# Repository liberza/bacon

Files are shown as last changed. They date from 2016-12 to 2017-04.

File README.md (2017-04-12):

# bacon - Balloon Ascent Controller

The goal of this project is to control the rate of ascent of two high-altitude
balloons, to keep at the same relative altitude as they ascend. 

A simulator is included in simulator/. Run tongs.py to start, then open client.html
in a browser. Power up the two payloads to begin auto-discovery. Once that is finished, 
the simulated flight begins and shows a live plot of progress.

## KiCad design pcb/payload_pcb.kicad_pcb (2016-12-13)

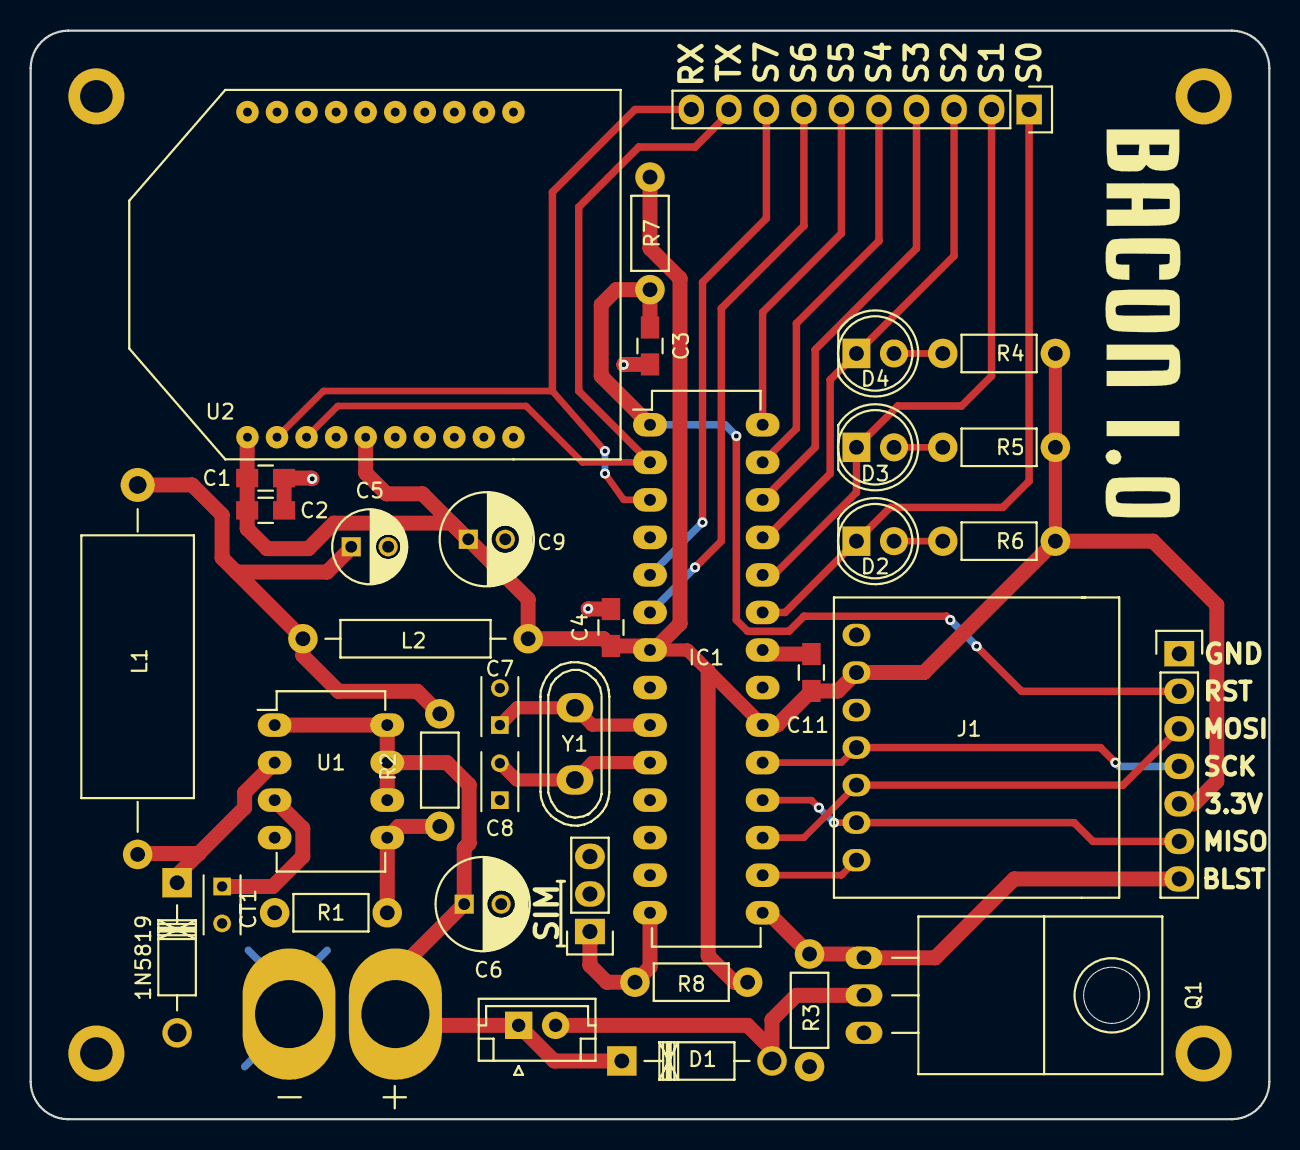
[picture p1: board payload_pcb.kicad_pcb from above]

Board: 2 copper layers, 83.8 x 73.7 mm, 37 parts (0 on the bottom side), 30 nets.

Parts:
1N5819: D5; Diode_DO-41_SOD81_Horizontal_RM10
C1, C2, C4, C11: CP1; C_0805_HandSoldering
C3: 0.1uF; C_0805_HandSoldering
C5: 22uF; C_Radial_D5_L11_P2.5
C6: 100 uF; C_Radial_D6.3_L11.2_P2.5
C7, C8: 22p; C_Rect_L4_W2.5_P2.5
C9: 100uF; C_Radial_D6.3_L11.2_P2.5
CT1: 160 pF; C_Rect_L4_W2.5_P2.5
D1: D; Diode_DO-41_SOD81_Horizontal_RM10
D2: Green; LED-5MM
D3: Yellow; LED-5MM
D4: Red; LED-5MM
IC1: ATMEGA328-P; DIP-28_W7.62mm_LongPads
J1: MS5607_Module
L1: 50 uH; Choke_Horizontal_RM25mm
L2: 1 uH; Choke_Horizontal_RM15mm
P1: BAT_TERMINALS; XT60
P2: CONN_01X10; Pin_Header_Straight_1x10
P3: CONN_01X03; Pin_Header_Straight_1x03
P4: CONN_01X07; Pin_Header_Straight_1x07
P5: VALVE; JST_EH_B02B-EH-A_02x2.50mm_Straight
Q1: Q1; TO-220_Neutral123_Horizontal
R1: 22k; Resistor_Horizontal_RM7mm
R2: 36k; Resistor_Horizontal_RM7mm
R3, R7: 4.7k; Resistor_Horizontal_RM7mm
R4, R5, R6: 270; Resistor_Horizontal_RM7mm
R8: 4.7K; Resistor_Horizontal_RM7mm
U1: MC33063A; DIP-8_W7.62mm_LongPads
U2: XBee_S3B
Y1: Crystal; Crystal_HC50-U_Vertical

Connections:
3.3V: C1.1, C2.1, C4.1, C9.1, C11.1, IC1.7, IC1.20, J1.2, L2.1, P4.5, R4.2, R5.2, R6.2, R7.1, R8.1, U2.1, U2.5
BALLAST: IC1.15, P4.7, Q1.1, R3.1
CSB: IC1.16, J1.7
GND: 1N5819.2, C1.2, C2.2, C3.2, C4.2, C5.2, C6.2, C7.2, C8.1, C9.2, C11.2, CT1.2, IC1.8, IC1.22, J1.1, J1.3, P1.1, P3.2, P3.3, P4.1, Q1.3, R1.2, R3.2, U1.4, U2.10
MISO: IC1.18, J1.6, P4.6
MODE: IC1.14, P3.1, R8.2
MOSI: IC1.17, J1.5, P4.3
unnamed: 1N5819.1, L1.1, U1.2
unnamed: C5.1, L1.2, L2.2, R2.2
unnamed: C7.1, IC1.9, Y1.1
unnamed: C8.2, IC1.10, Y1.2
unnamed: CT1.1, U1.3
unnamed: D1.2, P5.2, Q1.2
unnamed: D2.2, R6.1
unnamed: D3.2, R5.1
unnamed: D4.2, R4.1
unnamed: R1.1, R2.1, U1.5
RESET: C3.1, IC1.1, P4.2, R7.2
SCK: IC1.19, J1.4, P4.4
STATUS0: D2.1, IC1.23, P2.1
STATUS1: D3.1, IC1.24, P2.2
STATUS2: D4.1, IC1.25, P2.3
STATUS3: IC1.26, P2.4
STATUS4: IC1.27, P2.5
STATUS5: IC1.28, P2.6
STATUS6: IC1.6, P2.7
STATUS7: IC1.5, P2.8
VDD: C6.1, D1.1, P1.2, P5.1, U1.1, U1.6, U1.7, U1.8
XBEE_RX: IC1.3, P2.10, U2.2
XBEE_TX: IC1.2, P2.9, U2.3

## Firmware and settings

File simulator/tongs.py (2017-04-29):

#!/usr/bin/python3
import numpy as np
from datetime import datetime, timedelta
import time
import binascii
import websockets
import asyncio
import json

# local imports
from payload import Payload
from xbee import XBee
from liveplot import LivePlot
import bmp

# make this commandline args at some point. for now, this is completely fine.
MASS1 = 3.4
MASS2 = 3.3
#BALLAST = 0.581 # half liter bottle capacity, minus 10ml
BALLAST = 0.8 # 2L bottle filled halfway with 0.8kg/L isopropyl alcohol
PROFILE = "profiles/umhab52.json"

# Let's simulate some balloons.

async def run_sim(websocket, path):
    try:
        # If your XBee is somewhere else, change this.
        xb = XBee("/dev/xbee", 1200)
    except:
        print("XBee not connected. Try plugging it in or changing the default from /dev/xbee.")
        exit()

    # two payloads
    p1 = Payload(PROFILE, MASS1, BALLAST, "P1")
    p2 = Payload(PROFILE, MASS2, BALLAST, "P2")

    # First order of business: figure out who's who.
    print("Performing initial peering...")
    bmp.init_peering(p1, p2, xb)

    # Ok, we have two payloads.
    # Wait for one to request an altitude.
    print("Waiting for initial altitude requests...")

    launched = False
    time_launched = None
    p1_ready = False
    p2_ready = False
    p1_landed = False
    p2_landed = False
    while((p1_landed == False) or (p2_landed == False)):
        msg = None
        # just listen. the payloads will ask for altitudes.
        while(msg == None):
            msg = xb.rx()

        parsed = bmp.parse(msg)
        msg_type = parsed[0]

        if (msg_type == bmp.MSG_TYPES['WAT_REQUEST']):
            # Say "I am a simulator"
            addr = int.from_bytes(parsed[2], byteorder="big")
            xb.tx(parsed[1], addr)
        elif (msg_type == bmp.MSG_TYPES['ALT_REQUEST']):
            # Time to simulate.
            addr = int.from_bytes(parsed[1], byteorder="big")
            if (addr == p1.addr):
                p1_ready = True
                cur_p = p1
            elif (addr == p2.addr):
                p2_ready = True
                cur_p = p2
            else:
                print("Another payload?")
                continue
            
            ballast_time_ms = parsed[2]
            cur_p.drop_mass(ballast_time_ms)
            cur_time = time.time()
            last_time = cur_p.last_request_time
            last_alt_m = cur_p.last_alt/10.0
            if (launched):
                #cur_p.adjust_time(cur_time)
                p1.adjust_time(cur_time)
                p2.adjust_time(cur_time)
            else:
                #cur_p.last_request_time = cur_time
                p1.last_request_time = cur_time
                p2.last_request_time = cur_time
            # Send them their current alt.
            if (cur_p.alt() is not None):
                alt = cur_p.alt()
                cur_p.last_alt = alt
                # send the payload's alt
                xb.tx("s" + str(int(alt)), cur_p.addr)

                timestamp = datetime.fromtimestamp(cur_time).strftime("[%H:%M:%S]")
                #alt_m = cur_p.alt()/10.0 # decimeters to meters
                #speed = (alt_m-last_alt_m)/(cur_time-last_time)
                p1_alt_m = p1.alt()/10.0
                p2_alt_m = p2.alt()/10.0
                #if (speed == None):
                #    speed = 0
                #print("{0} {1}: alt={2:.1f}m speed={3:.2f}m/s mass={4:.3f}kg drop_time={5}".format(timestamp,cur_p.name,alt_m,speed,cur_p.mass,ballast_time_ms))
                #print("P1 alt: {0}, P2 alt: {1}, Delta alt: {2}, P1 mass: {3}, P2 mass: {4}".format(p1_alt_m, p2_alt_m, p1_alt_m - p2_alt_m, p1.mass, p2.mass))
                await websocket.send('{{"p1_a": {0}, "p2_a": {1}, "p1_m": {2}, "p2_m": {3}, "dist": {4}}}'.format(p1_alt_m, p2_alt_m, p1.mass, p2.mass, p1_alt_m - p2_alt_m))

                # update graph
                #if (time_launched is not None):
                    #if (cur_p.name == "P1"):
                        #lp.update_line(cur_time - time_launched, alt_m, p1_line)
                    #elif (cur_p.name == "P2"):
                        #lp.update_line(cur_time - time_launched, alt_m, p2_line)
            else:
                # if alt is None, the payload finished simulation.
                if (cur_p.addr == p1.addr):
                    p1_landed = True
                elif (cur_p.addr == p2.addr):
                    p2_landed = True
                continue
            
            if (p1_ready and p2_ready and launched == False):
                launched = True
                time_launched = time.time()
                time_elapsed = 0
                print("Launched!")

        elif (msg_type == bmp.MSG_TYPES['WAT_REQUEST']):
            # Respond, saying "I am the simulator".
            addr = int.from_bytes(parsed[2], byteorder="big")
            xb.tx(parsed[1], addr)


if __name__ == "__main__":
    # ASCII art adapted from www.chris.com/ASCII/index.php?art=objects/balloons
    print('''
          ,'````',
    .`',.'        `..'``',      ____
  ,'                     `', .-'    '-.                                 
 ;                        ..' /)       '.         ,'``',  ,..,   ,..,
  ',            ,.,    .'`/  (/          \     ,.'      '`    '.'    ;
    '.,.`'.,,,.`   `''`  ;                ;  ,`                       ',
                         |                | ;                           ;
                         |                | `.,     ;    ,...         ,'
             ____        ;                ;    `.,.' `,.'    `,.     ;
          .-'    '-.      \              /                      `.,,'
        .' /)       '.     '.          .'   
       /  (/          \      '-._  _.-'      
      ;                ;         )(           
      |                |        (__)          
      |    ( ͡° ͜ʖ ͡°)    |         /            ╔╦╗╔═╗╔╗╔╔═╗╔═╗
      ;                ;         |             ║ ║ ║║║║║ ╦╚═╗
       \              /          ;             ╩ ╚═╝╝╚╝╚═╝╚═╝
        '.          .'          /     The on-ground simulator for BACON
          '-._  _.-'          |--|        
              )(              |  |    
             (__)             |__|     
              |                ;     
              |                /
              |               ;  
              ;               ;
''')
    print("Waiting for websocket connection...")
    start_server = websockets.serve(run_sim, '127.0.0.1', 5678)
    asyncio.get_event_loop().run_until_complete(start_server)
    asyncio.get_event_loop().run_forever()

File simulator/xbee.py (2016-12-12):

#!/usr/bin/python3
import serial
import queue
import time
import binascii

# class for managing XBee API mode 
class XBee():
    # Bytes which need to be escaped in frames
    SPECIAL_BYTES = {
        'FRAME_DELIM':  0x7E,
        'ESCAPE':       0x7D,
        'XON':          0x11,
        'XOFF':         0x13,
    }

    # Digimesh broadcast addr
    BROADCAST = 0x000000000000FFFF

    # Digimesh frame types
    FRAME_TYPES = {
        'AT':           0x08,
        'AT_QPV':       0x09,
        'TX':           0x10,
        'EXPLICIT_TX':  0x11,
        'REMOTE':       0x17,
        'AT_RESP':      0x88,
        'MODEM_STATUS': 0x8A,
        'TX_STATUS':    0x8B,
        'ROUTE_INFO':   0x8D,
        'RX':           0x90,
        'EXPLICIT_RX':  0x91,
        'NODE_ID':      0x95,
        'REMOTE_RESP':  0x97,
    }

    BUF_FULL_TIMEOUT = 5

    # queue to hold validated frames
    rx_queue = queue.Queue()
    # buffer to hold partial frames
    rx_buf = bytearray()

    def __init__(self, devfile, baud):
        self.serial = serial.Serial(port=devfile, 
                                    baudrate=baud,
                                    parity=serial.PARITY_NONE,
                                    stopbits=serial.STOPBITS_ONE,
                                    bytesize=serial.EIGHTBITS
                                    )
        self.serial.flush()
        self.max_frame = 255

    def tx(self, data, dest=0x000000000000FFFF, opts=0x00):
        '''
        data is an unescaped string.
        dest is the 64-bit digimesh address to tx to.
        opts are the frame options.
        '''
        frame_size = len(data) + 14     # tx api frame has 14 bytes overhead
        if (frame_size > self.max_frame):
            print("Frame too long, not sending.")
            return False

        frame = bytearray(((frame_size >> 8) & 0x0FF, 
                           (frame_size & 0x0FF),
                           self.FRAME_TYPES['TX'],
                           0x00,
                           # destination
                           (dest >> 56) & 0x0FF,
                           (dest >> 48) & 0x0FF,
                           (dest >> 40) & 0x0FF,
                           (dest >> 32) & 0x0FF,
                           (dest >> 24) & 0x0FF,
                           (dest >> 16) & 0x0FF,
                           (dest >> 8) & 0x0FF,
                           (dest & 0x0FF),
                           0xFF, # reserved
                           0xFE, # reserved
                           0x00, # broadcast radius (default 0x00 for radius=max hops)
                           0x00, # tx options (default, use whatever is already set)
                           ))

        # append the data
        frame += bytearray(data.encode())

        # append checksum
        frame.append(0xFF - (sum(frame[2:]) & 0x0FF))
        
        # escape the frame
        frame = self.escape(frame)

        # prepend the unescaped delimiter
        frame = bytearray(b'\x7E') + frame

        return self.serial.write(frame)

    def rx(self):
        '''
        Read bytes from serial if any are waiting.
        Then validate frames and add to rx_queue.
        '''
        received = False
        num_bytes = self.serial.in_waiting
        self.rx_buf.extend(self.serial.read(num_bytes))
        # each sequence is a frame. split at the delimiter.
        sequence = self.rx_buf.split(bytes(b'\x7E'))        
        for s in sequence:
            frame = self.validate_frame(s)
            if (frame is not None):
                self.rx_queue.put(frame, self.BUF_FULL_TIMEOUT)
                received = True

        if (received == True):
            self.rx_buf = bytearray()
            return self.rx_queue.get()

        else:
            return None

    def parse_frame(self, frame):
        '''
        Parse a frame. Figure out what type it is, and return the relevant data.
        '''
        for frametype, value in self.FRAME_TYPES.items():
            if frame[2] == value:
                break;

        if (value == self.FRAME_TYPES['AT_RESP']):
            pass
        elif (value == self.FRAME_TYPES['MODEM_STATUS']):
            pass
        elif (value == self.FRAME_TYPES['TX_STATUS']):
            pass
        elif (value == self.FRAME_TYPES['ROUTE_INFO']):
            pass
        elif (value == self.FRAME_TYPES['RX']):
            source = frame[3:10]
            opts = frame[13]
            data = frame[14:-1]
            return data
        elif (value == self.FRAME_TYPES['EXPLICIT_RX']):
            pass
        elif (value == self.FRAME_TYPES['TX']):
            # just for debugging. the only time this should ever show up is
            # if you have a serial cable hooked up to the TX pin of the xbee.
            pass
        elif (value == self.FRAME_TYPES['NODE_ID']):
            pass
        elif (value == self.FRAME_TYPES['REMOTE_RESP']):
            pass
        else:
            raise Exception("Frame has invalid frame type.")
        return None

    def escape(self, data):
        ''' Put an escape character before a special character, and escape it. '''
        escaped = bytearray()
        for byte in data:
            if byte in self.SPECIAL_BYTES.values():
                escaped.append(self.SPECIAL_BYTES['ESCAPE'])
                escaped.append(byte ^ 0x20)
            else:
                escaped.append(byte)
        return escaped

    def unescape(self, data):
        ''' Think "escape", but the opposite of that. '''
        unescaped = bytearray()
        last_escaped = False
        # create an iterator from range() so we can use next() on it
        q = iter(range(len(data)))
        for i in q:
            if (last_escaped):
                unescaped.append(data[i] ^ 0x20)
                last_escaped = False
            elif data[i] == self.SPECIAL_BYTES['ESCAPE']:
                last_escaped = True
            else:
                unescaped.append(data[i])
        return unescaped
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

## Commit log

2016-10-11 add serial.c. modify definition of serial_init() to allow for easier configuration of UART.
2016-10-16 much progress on XBee.tx(). untested beyond watching the TX LED light up on the breakout board when running it.
2016-10-16 functions for initializing gpio and operating solenoid valve
2016-10-16 add XBee.rx(). need to do frame validation
2016-10-16 fixed a few bugs. checksum now verifies correctly and length is computed properly
    [xbee.py]
2016-10-16 reorganize constants, add new FRAME_TYPES dict of constants.
2016-10-16 interrupt reads byte and writes to buffer.
2016-10-16 simplified interrupt routine
2016-10-23 fix all compilation warnings and errors. ISR() is a macro, not a function to declare.
    [xbee.py]
2016-10-23 move ISR for rx to xbee.c, because it will swap buffers when frame delimiter is reached.
2016-10-23 use SPECIAL_BYTES instead of hardcoding frame delim
2016-10-24 fix frame_types and special_bytes declarations
2016-10-27 make interrupt rx buffer volatile
2016-11-06 replacing pingpong.h/c with rbuf.h/c. a ring buffer is more appropriate for this use-case.
2016-11-11 fix xbee.py. seems to work great now.
    [xbee.py]
2016-11-11 fix frame parsing
2016-11-11 fixing parse frame and checksum in xbee.py. also confirmed that unescaping in xbee.c seems to work fine.
    [xbee.py]
2016-11-13 Found a potential root cause for validate_frame() not working correctly. Was not shifting the rbuf on fail conditions, so it would just fail again, and again, and again, and again, and again, and aga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
    [xbee.py]
2016-11-13 disable interrupts during tx
2016-11-13 Found bug, in process of squashing. Was abusing ATOMIC_BLOCK(). Probably don't even need it.
    [xbee.py]
2016-11-13 frame parsing mostly working. some strange repetition going on, but the meat is all there.
2016-11-14 fixed bug where validate_frame() thought the frame was larger than it actually was, when multiple bytes were escaped.
    [xbee.py]
2016-11-15 add nice lil scripts for resetting buspirate.. These are for the build process, not related to the rest of the project at all.
    [bmp.py, flight.py]
2016-11-16 simple timers are working.
2016-11-17 added function for reading sensor adc
2016-11-17 completed function for returning atmospheric pressure (untested)
2016-12-10 update makefile. turn on optimization, and add lines to support another programmer. also adding comments in xbee.c. also, more solenoid testing in main.c.
2016-12-10 green LED now blinks while in peering mode, stays solid while in flight
2016-12-11 added buspirate power
2016-12-11 fixed bug where peering would loop infinitely.
    [bmp.py]
2016-12-12 fix buffer overflow in frame parsing.
2016-12-12 Tweak control params. Set frame ID to 0x00 to avoid TX_STATUS packets, this has seriously improved transmission reliability.
2016-12-12 Peering reliability improved. Also decreased all timeouts and timer thresholds, the XBees and AVRs can handle it and it makes everything more responsive.
2016-12-12 More cleanup. Looking good, time to print it
2016-12-12 successfully reading pressure (bar) and temperature (celsius)
2016-12-13 add pcb files
    [payload_pcb.kicad_pcb, payload_pcb.sch]
2017-03-31 temporarily turn off graph, change print style
    [payload_pcb.sch]
2017-03-31 Increase D in control, reduce threshold, and reduce number of samples for averaging. Also, harden the xbee code against edge case where frame length = MAX_BUF_LEN.
2017-04-02 Calibrate control parameters more. Best yet. Changed payload ballast to 1L.
2017-04-29 was having an issue with flight mode... the issue was = instead of ==...
    [listen.py, tongs.py]
2017-04-29 Fixed a lot of things........ like flight mode, altimeter calibration, initializing memory...
